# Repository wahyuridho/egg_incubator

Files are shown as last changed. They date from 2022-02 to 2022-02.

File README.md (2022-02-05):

# egg_incubator

Hai ini adalah projek penetas telur yang saya buat, yang mana bertujuan untuk membuat sebuah alat yang dapat digunakan untuk menetaskan telur dari burung puyuh
alat & bahan
1. Arduino pro mini / arduino nano (sesuaikan dengan design PCB)
2. DS18B20
3. LCD 16x2
4. Relay
5. 3 Buah Push Button
6. Optocoupler PC817
7. Resistor 4k7, 470, 120
8. Transistor 2N3905 or ..
9. Diode 1N4007 or ...
10. Jack DC barrel
11. Capacitor 47uF, 10uF, 0.1uF
12. IC L7805

Anda bisa melihat untuk komponen yang digunakan dengan melihat tampilan 3D dari Kicad

note : untuk komponen yang tidak muncul 3D design nya bisa dicari pada folder 3D Model

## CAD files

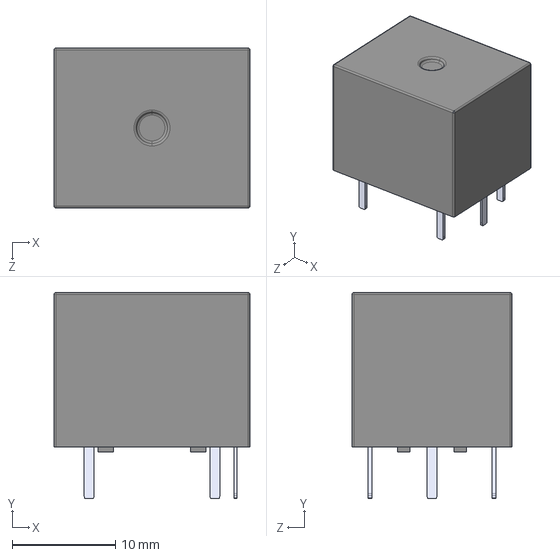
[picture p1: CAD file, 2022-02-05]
3D Model/JQC-3F-1C-24VDC--3DModel-STEP-56544.STEP
19.0 x 20.0 x 15.5 mm

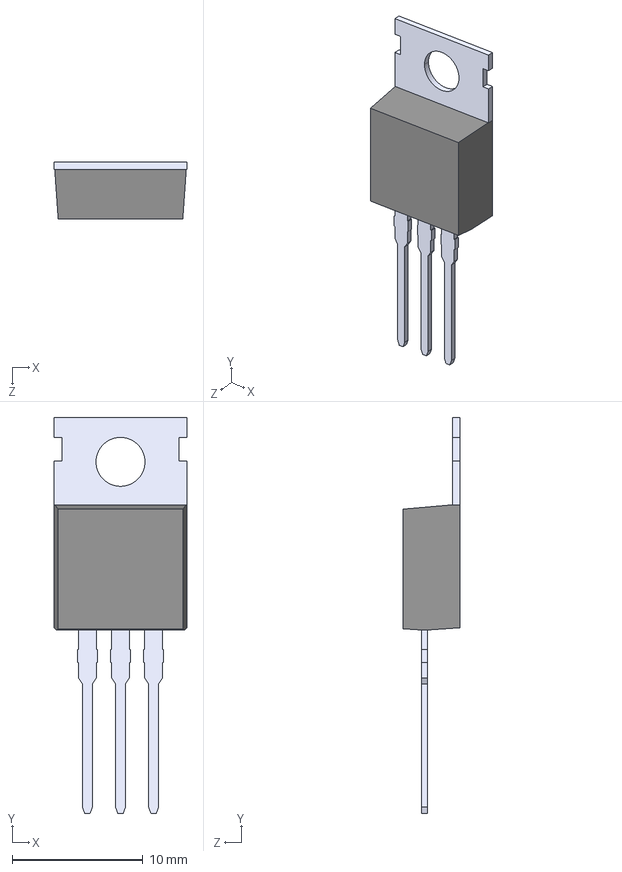
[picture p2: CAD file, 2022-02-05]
komponen/L7805CV/L7805CV.step
10.2 x 30.3 x 4.35 mm

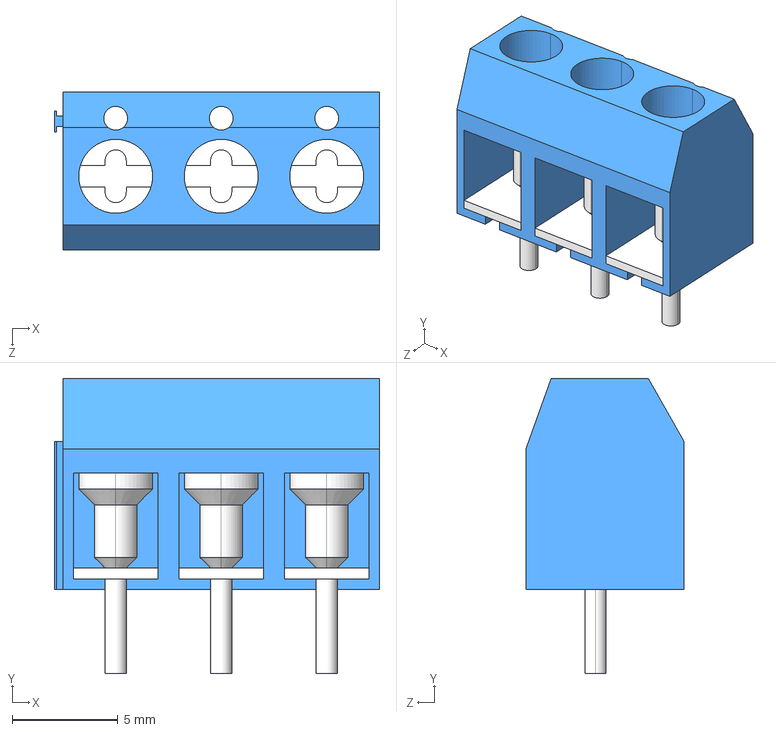
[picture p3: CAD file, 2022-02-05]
3D Model/KF301-3P.stp
15.4 x 14.0 x 7.50 mm

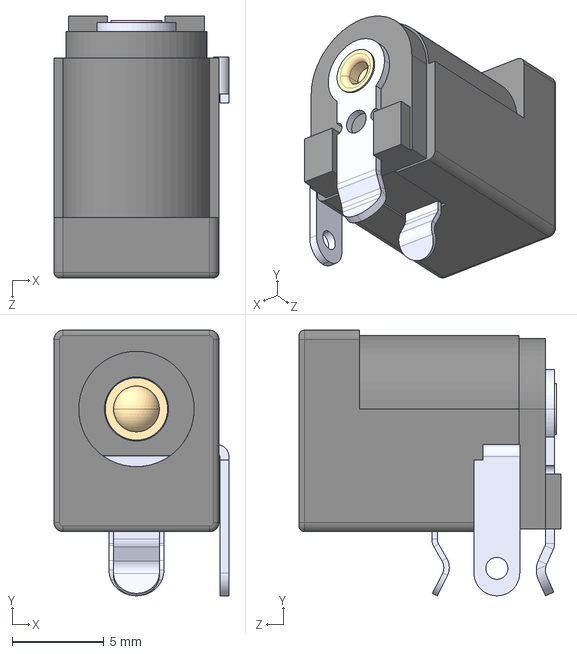
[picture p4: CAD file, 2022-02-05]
3D Model/DCJ250-10-A-K1-K--3DModel-STEP-56544.STEP
9.55 x 14.5 x 14.3 mm

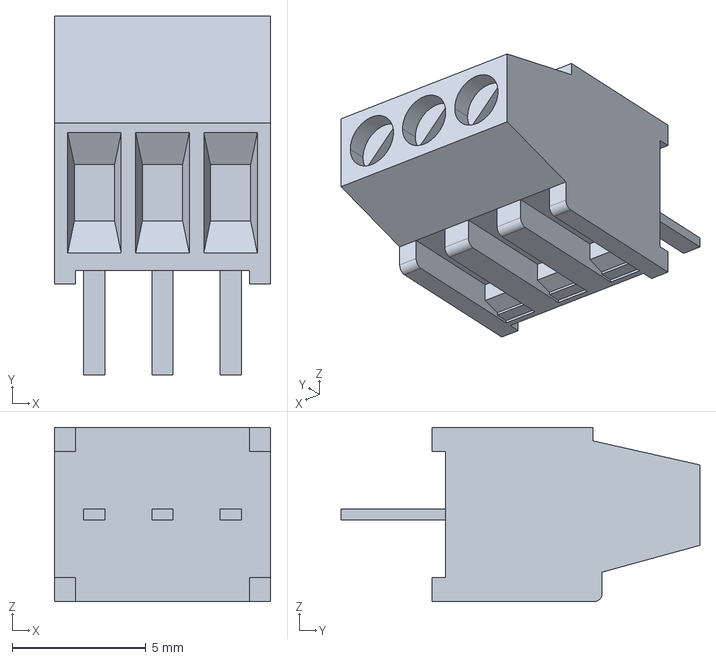
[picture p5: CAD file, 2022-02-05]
komponen/282834-3/282834-3.step
8.08 x 13.4 x 6.50 mm

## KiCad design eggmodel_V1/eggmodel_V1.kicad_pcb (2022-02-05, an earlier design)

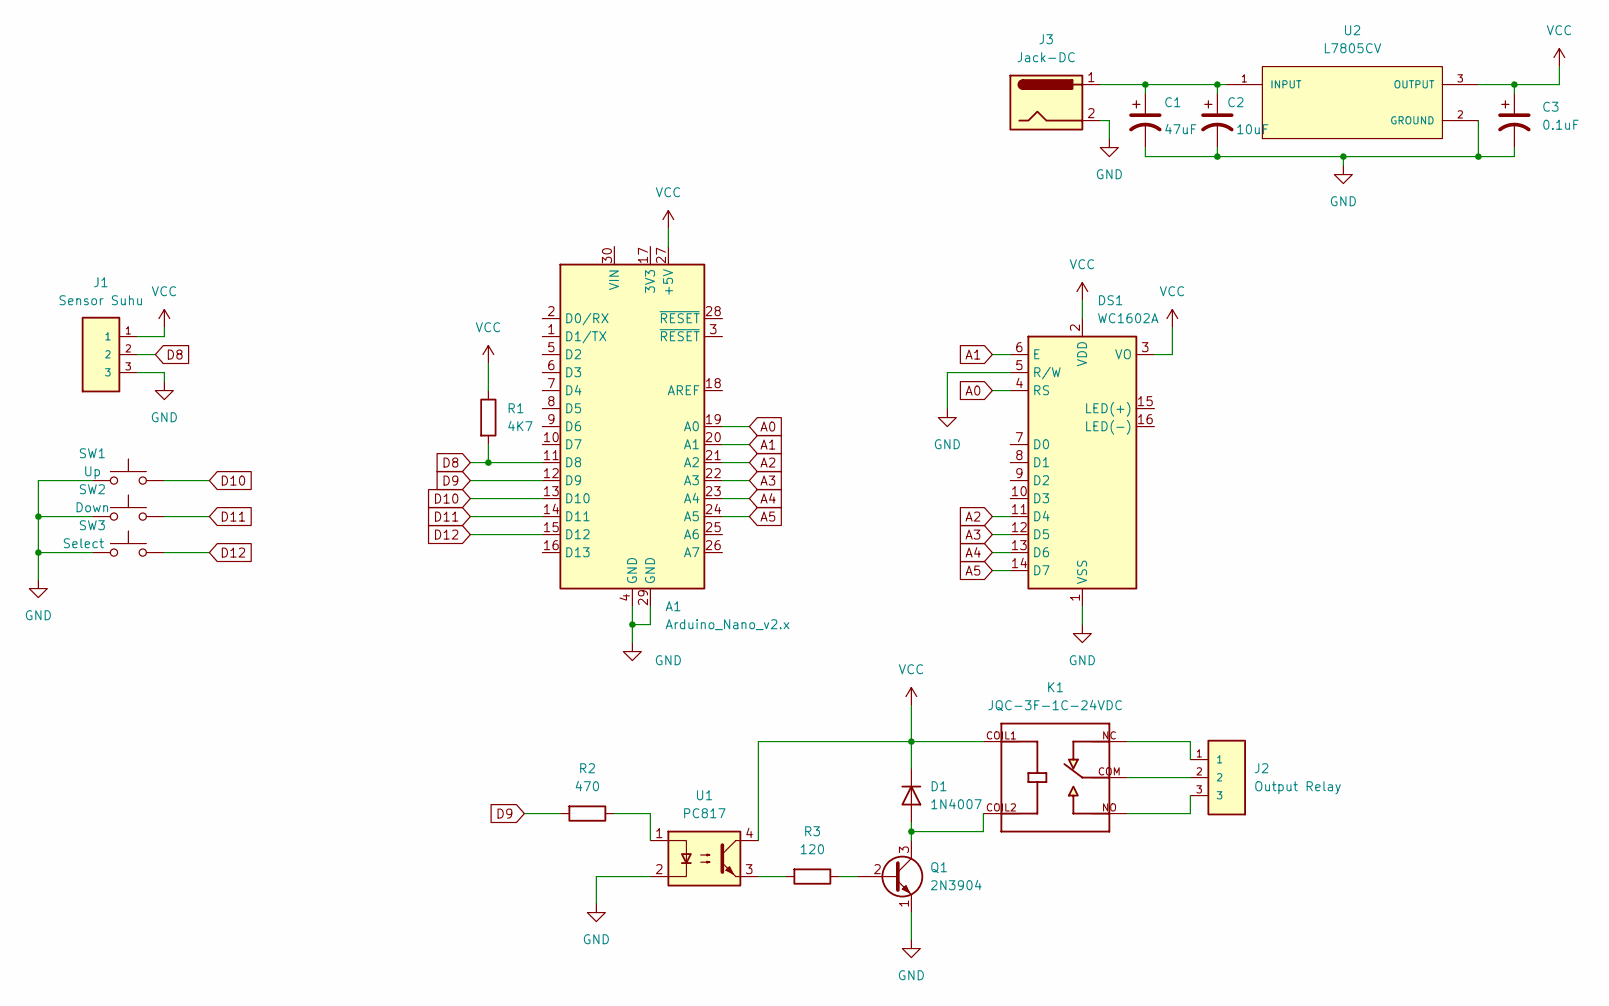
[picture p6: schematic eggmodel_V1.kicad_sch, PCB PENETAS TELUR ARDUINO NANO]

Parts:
A1: Arduino_Nano_v2.x; Arduino_Nano
C1: 47uF; CP_Radial_D6.3mm_P2.50mm
C2: 10uF; CP_Radial_D6.3mm_P2.50mm
C3: 0.1uF; CP_Radial_D6.3mm_P2.50mm
D1: 1N4007; D_DO-41_SOD81_P10.16mm_Horizontal
DS1: WC1602A
J1: Sensor Suhu; TE_282834-3
J2: Output Relay; TE_282834-3
J3: Jack-DC; BarrelJack_Horizontal
K1: JQC-3F-1C-24VDC; RELAY_JQC-3F-1C-24VDC; PARTREV N/A
Q1: 2N3904; TO-92_Wide
R1: 4K7; R_Axial_DIN0204_L3.6mm_D1.6mm_P7.62mm_Horizontal
R2: 470; R_Axial_DIN0204_L3.6mm_D1.6mm_P7.62mm_Horizontal
R3: 120; R_Axial_DIN0204_L3.6mm_D1.6mm_P7.62mm_Horizontal
SW1: Up; SW_PUSH_6mm
SW2: Down; SW_PUSH_6mm
SW3: Select; SW_PUSH_6mm
U1: PC817; DIP-4_W7.62mm
U2: L7805CV; TO255P1040X460X1968-3; PARTREV 36

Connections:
A0: A1.19 (A0), DS1.4 (RS)
A1: A1.20 (A1), DS1.6 (E)
A2: A1.21 (A2), DS1.11 (D4)
A3: A1.22 (A3), DS1.12 (D5)
A4: A1.23 (A4), DS1.13 (D6)
A5: A1.24 (A5), DS1.14 (D7)
D8: A1.11 (D8), J1.2, R1.2
D9: A1.12 (D9), R2.2
D10: A1.13 (D10), SW1.2
D11: A1.14 (D11), SW2.2
D12: A1.15 (D12), SW3.2
GND: A1.4 (GND), A1.29 (GND), C1.2, C2.2, C3.2, DS1.1 (VSS), DS1.5 (R/W), J1.3, J3.2, Q1.1 (E), SW1.1, SW2.1, SW3.1, U1.2, U2.2 (GROUND)
unnamed: C1.1, C2.1, J3.1, U2.1 (INPUT)
unnamed: D1.2 (A), K1.COIL2, Q1.3 (C)
unnamed: J2.1, K1.NC
unnamed: J2.2, K1.COM
unnamed: J2.3, K1.NO
unnamed: Q1.2 (B), R3.1
unnamed: R2.1, U1.1
unnamed: R3.2, U1.3
VCC: A1.27 (+5V), C3.1, D1.1 (K), DS1.2 (VDD), DS1.3 (VO), J1.1, K1.COIL1, R1.1, U1.4, U2.3 (OUTPUT)

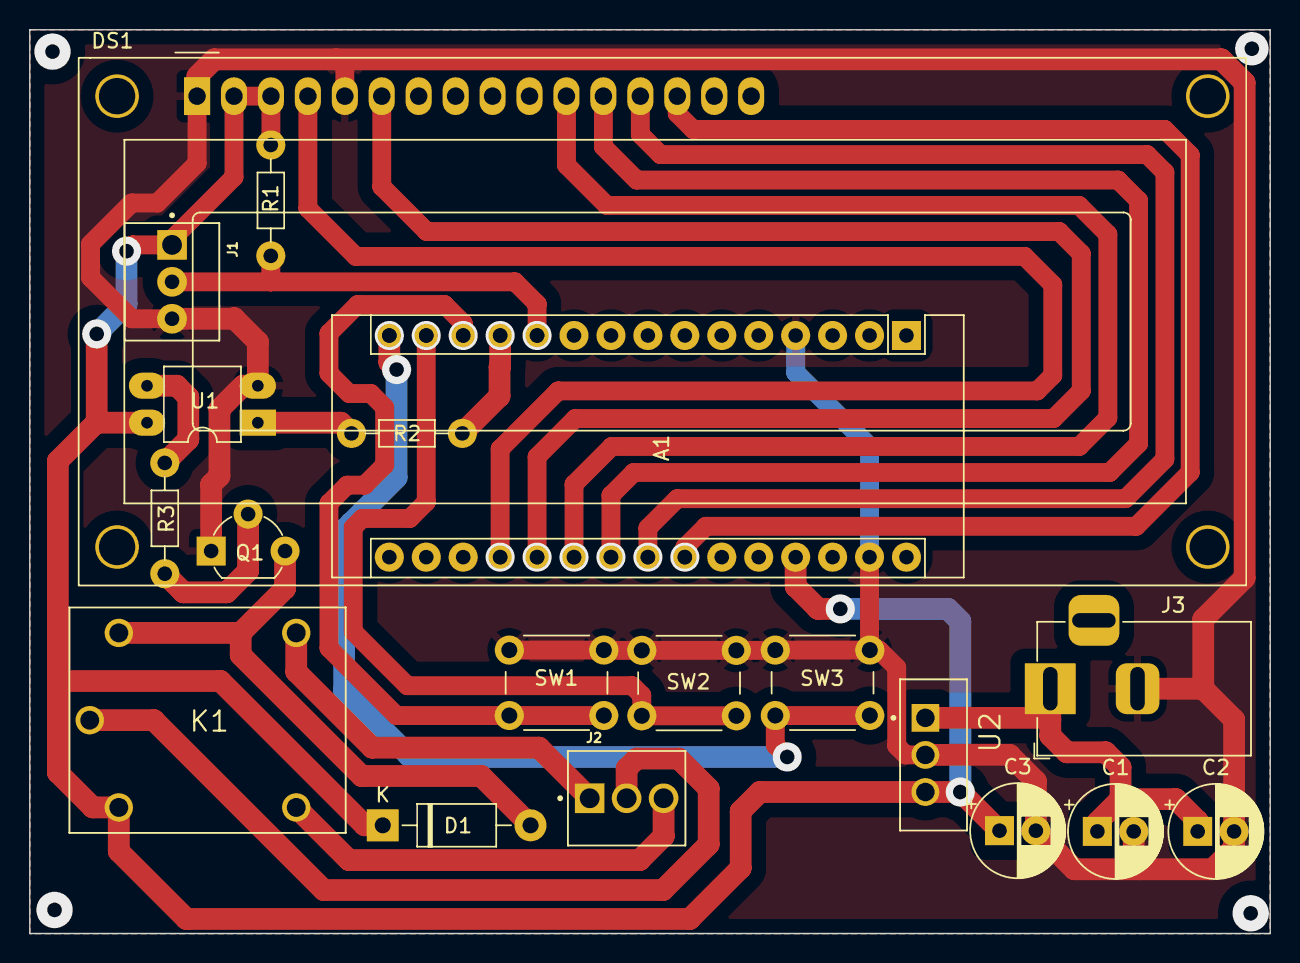
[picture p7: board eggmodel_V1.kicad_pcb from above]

Board: 2 copper layers, 85.3 x 62.1 mm, 19 parts (0 on the bottom side), 21 nets.

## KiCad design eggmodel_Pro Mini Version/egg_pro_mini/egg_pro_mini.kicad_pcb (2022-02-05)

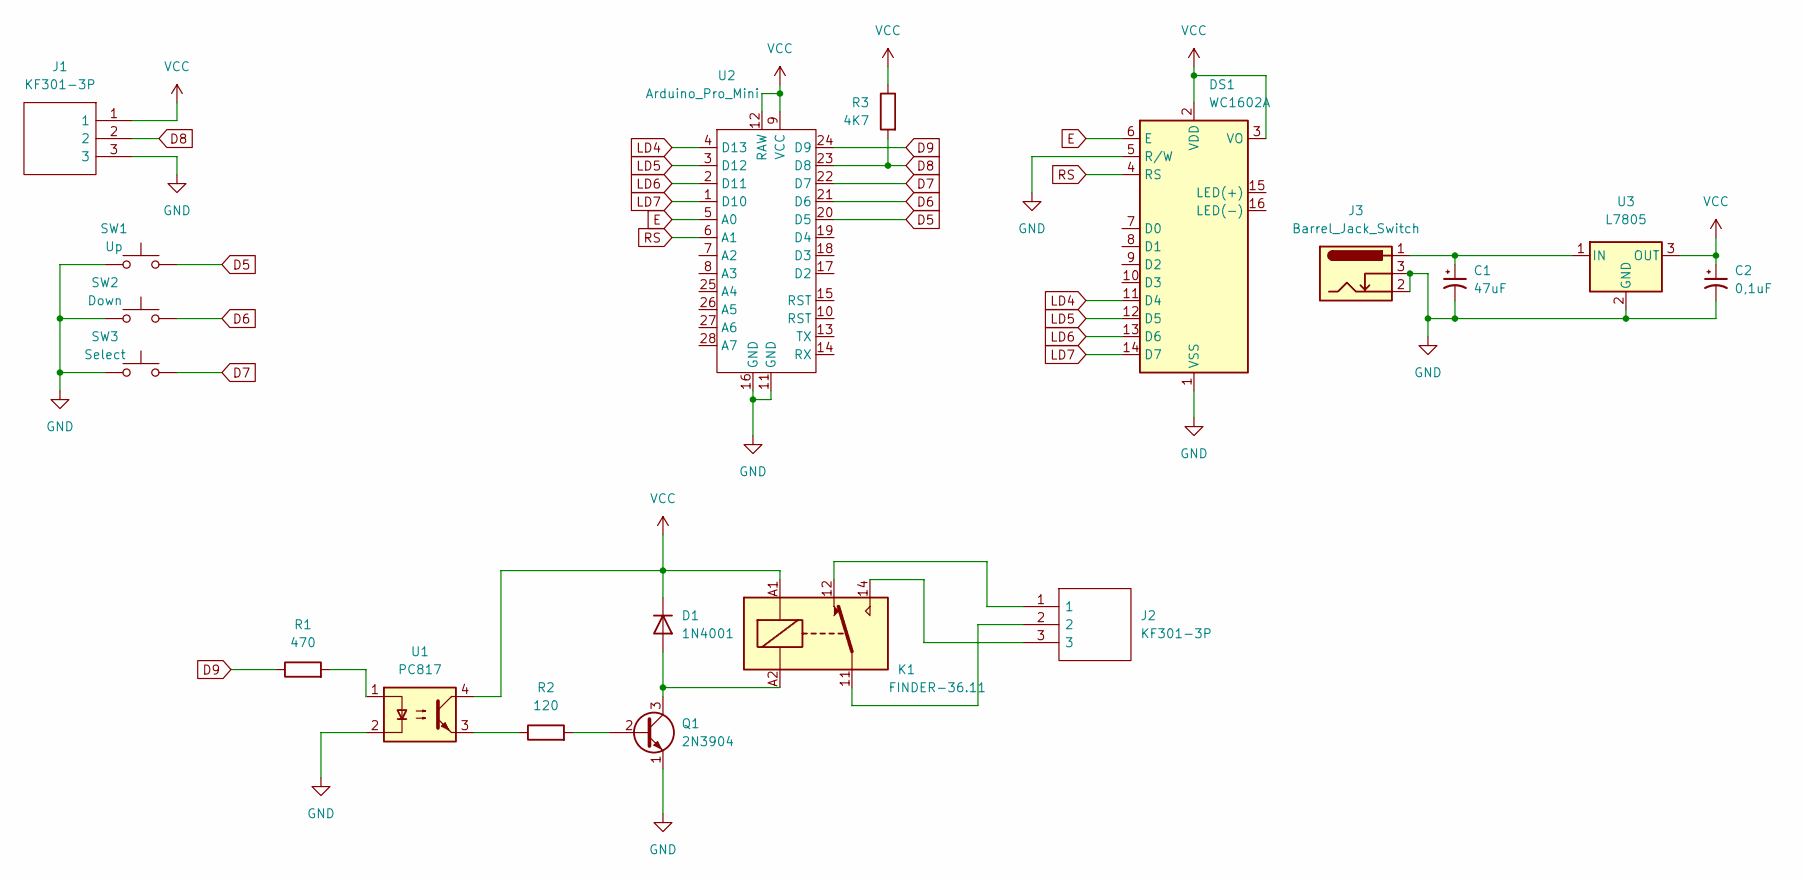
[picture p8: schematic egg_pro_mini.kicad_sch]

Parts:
C1: 47uF; CP_Radial_D5.0mm_P2.50mm
C2: 0,1uF; CP_Radial_D5.0mm_P2.50mm
D1: 1N4001; D_DO-41_SOD81_P10.16mm_Horizontal
DS1: WC1602A
J1, J2: KF301-3P; KF3013P; Manufacturer_Part_Number KF301-3P
J3: Barrel_Jack_Switch; BarrelJack_Horizontal
K1: FINDER-36.11; Relay_SPDT_Finder_36.11
Q1: 2N3904; TO-92_Wide
R1: 470; R_Axial_DIN0204_L3.6mm_D1.6mm_P7.62mm_Horizontal
R2: 120; R_Axial_DIN0204_L3.6mm_D1.6mm_P7.62mm_Horizontal
R3: 4K7; R_Axial_DIN0204_L3.6mm_D1.6mm_P7.62mm_Horizontal
SW1: Up; SW_PUSH_6mm_H8.5mm
SW2: Down; SW_PUSH_6mm_H8.5mm
SW3: Select; SW_PUSH_6mm_H8.5mm
U1: PC817; DIP-4_W7.62mm
U2: Arduino_Pro_Mini; arduino_pro_mini_mega168
U3: L7805; TO255P1040X460X1968-3

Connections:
D5: SW1.2, U2.20 (D5)
D6: SW2.2, U2.21 (D6)
D7: SW3.2, U2.22 (D7)
D8: J1.2, R3.2, U2.23 (D8)
D9: R1.1, U2.24 (D9)
E: DS1.6 (E), U2.5 (A0)
GND: C1.2, C2.2, DS1.1 (VSS), DS1.5 (R/W), J1.3, J3.2, J3.3, Q1.1 (E), SW1.1, SW2.1, SW3.1, U1.2, U2.11 (GND), U2.16 (GND), U3.2 (GND); also elsewhere on the board
LD4: DS1.11 (D4), U2.4 (D13)
LD5: DS1.12 (D5), U2.3 (D12)
LD6: DS1.13 (D6), U2.2 (D11)
LD7: DS1.14 (D7), U2.1 (D10)
unnamed: C1.1, J3.1, U3.1 (IN)
unnamed: D1.2 (A), K1.A2, Q1.3 (C)
unnamed: J2.1, K1.12
unnamed: J2.2, K1.11
unnamed: J2.3, K1.14
unnamed: Q1.2 (B), R2.2
unnamed: R1.2, U1.1
unnamed: R2.1, U1.3
RS: DS1.4 (RS), U2.6 (A1)
VCC: C2.1, D1.1 (K), DS1.2 (VDD), DS1.3 (VO), J1.1, K1.A1, R3.1, U1.4, U2.9 (VCC), U2.12 (RAW), U3.3 (OUT); also elsewhere on the board

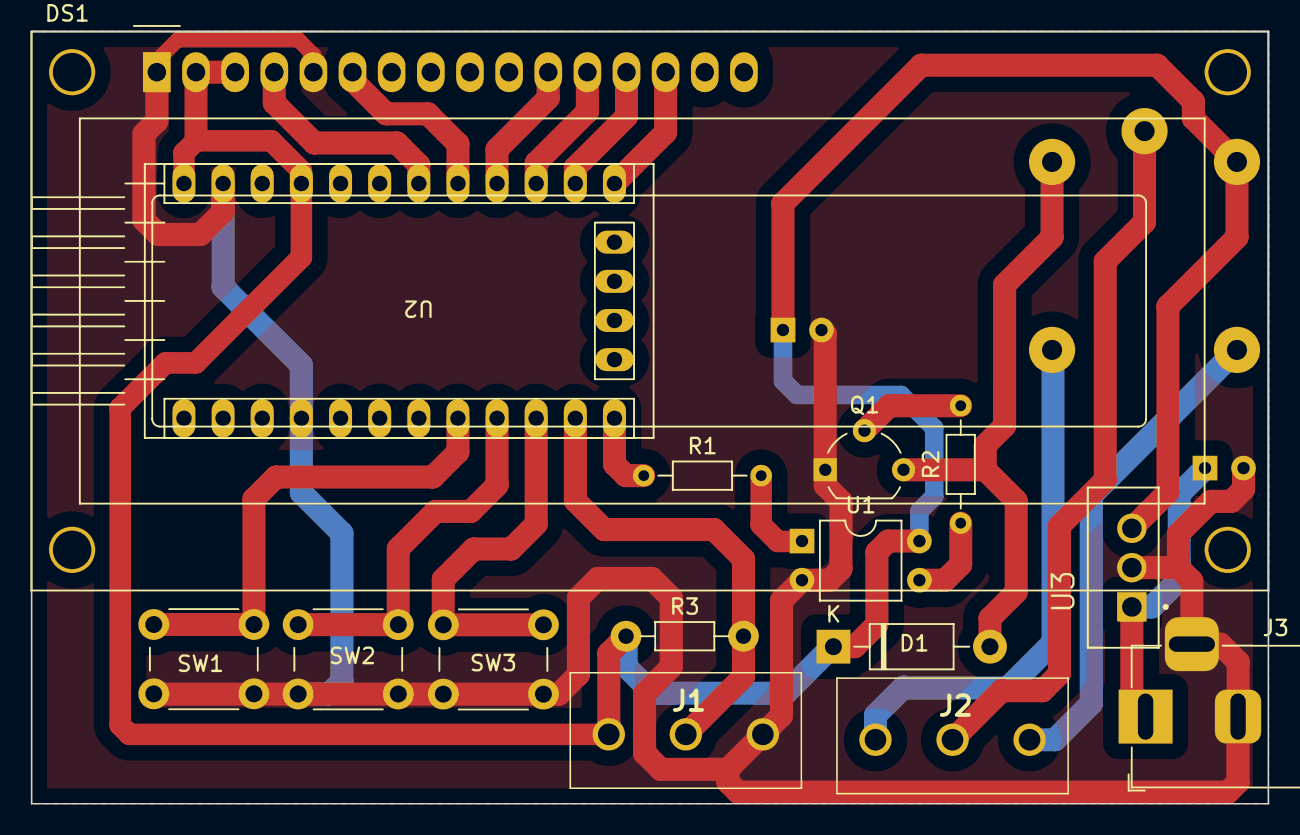
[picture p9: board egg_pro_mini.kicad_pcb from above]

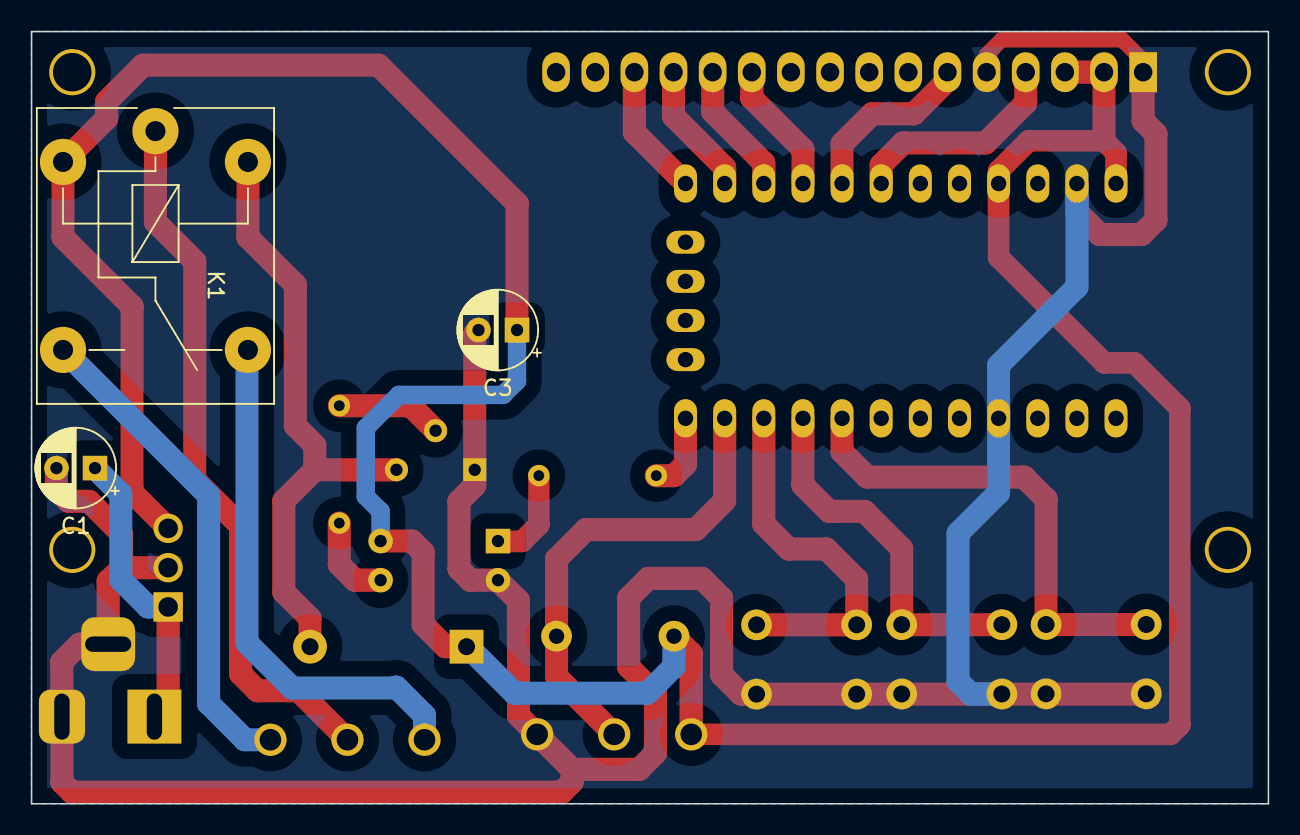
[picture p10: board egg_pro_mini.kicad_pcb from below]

Board: 2 copper layers, 80.3 x 50.1 mm, 18 parts (3 on the bottom side), 21 nets.

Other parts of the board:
C3: 0,1uF; CP_Radial_D5.0mm_P2.50mm

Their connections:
GND: C3.2; also elsewhere on the board
VCC: C3.1; also elsewhere on the board

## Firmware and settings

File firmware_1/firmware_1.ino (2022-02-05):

#include <Wire.h> 
#include <LiquidCrystal_I2C.h>
#include <EEPROM.h>
#include <OneWire.h>
#include <DallasTemperature.h>
#define ONE_WIRE_BUS 2

LiquidCrystal_I2C lcd(0x27,20,4);  // set the LCD address to 0x27 for a 16 chars and 2 line display
OneWire oneWire(ONE_WIRE_BUS);
DallasTemperature sensors(&oneWire);

int upButton = 10;
int downButton = 11;
int selectButton = 12;
int lamp = 9;
int count = 0;

void setup()
{
  Serial.begin(9600);
  sensors.begin();
  lcd.begin();
  lcd.clear();
  pinMode(upButton, INPUT_PULLUP);
  pinMode(downButton, INPUT_PULLUP);
  pinMode(selectButton, INPUT_PULLUP);
  pinMode(lamp, OUTPUT);
}


void loop()
{
  int up, down, selectbtn;
  sensors.requestTemperatures();
  up = digitalRead(upButton);
  down = digitalRead(downButton);
  selectbtn = digitalRead(selectButton);
  byte readEEPROM = EEPROM.read(0);
  float suhu = sensors.getTempCByIndex(0);
  byte degree = B11011111;
  
  if(readEEPROM){
    lcd.setCursor(0,0);  
    lcd.print("Suhu Saat Ini");
    lcd.setCursor(0,1);
    lcd.print(suhu, 1);
    lcd.write(degree);
    lcd.print("C");

    if(selectbtn == LOW){
      setSuhu(up, down, selectbtn);
    }

    if(suhu >= readEEPROM){
      digitalWrite(lamp, HIGH);  
    }else{
      digitalWrite(lamp, LOW);  
    }
    
  }else{
    setSuhu(up, down, selectbtn);
  }
  Serial.print(readEEPROM);
  delay(1000);
}

void setSuhu(int up, int down, int selectbtn){
  lcd.clear();
  lcd.setCursor(0,0);
  lcd.print("Set Temperature");
  if(up == LOW){
    countUp();
    lcd.setCursor(0,1);
    lcd.print(count);
    delay(100);
  }else if(down == LOW){
    countDown();
    lcd.setCursor(0,1);
    lcd.print(count);
    delay(100);    
  }
  if(selectbtn == LOW){
    EEPROM.write(0,count);
    lcd.clear();
    lcd.setCursor(0,0);
    lcd.print("Temperature Saving");
    delay(2000);
  } 
}

int countUp(){
  return count++;  
}

int countDown(){
  count --;
  if(count < 0){
    count = 0;  
  }
  return count;
}
